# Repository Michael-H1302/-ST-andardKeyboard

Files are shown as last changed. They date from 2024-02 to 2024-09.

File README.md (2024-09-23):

A custom keyboard design made with KiCad. The Design uses a STM32 Blue Pill Microcontroller featuring red led backlight that can be controlled in three groups (two rows per group). Don't get confused by the name HotKeyBoard. I just made use of some previous work and derived it from an already existing KiCad project. 
The keyboard design supports standard mechanical switches like the Cherry MX and the Gateron. Due to the LED placement below the actual switch footprint, even switches without an
extra space for the LED are supported.

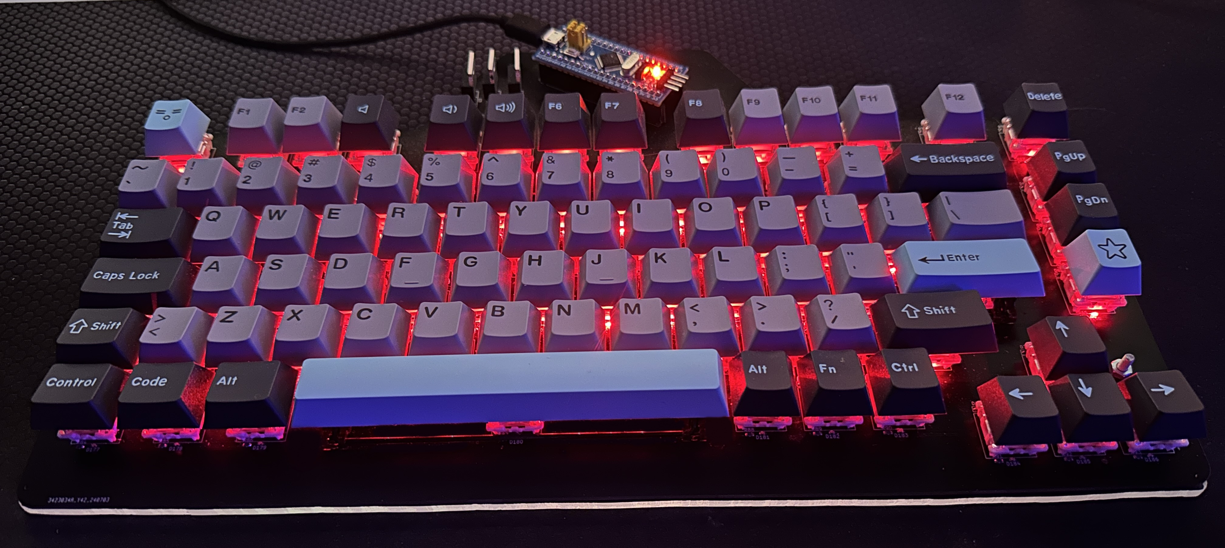
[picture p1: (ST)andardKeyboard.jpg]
Keyboard


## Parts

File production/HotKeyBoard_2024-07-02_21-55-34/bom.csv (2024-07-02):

Designator | Footprint | Quantity | Value | LCSC Part #
D1, D10, D11, D12, D13, D14, D15, D16, D17, D18, D19, D2, D20, D21, D22, D23, D24, D25, D26, D27, D28, D29, D3, D30, D31, D32, D33, D34, D35, D36, D37, D38, D39, D4, D40, D41, D42, D43, D44, D45, D46, D47, D48, D49, D5, D50, D51, D52, D53, D54, D55, D56, D57, D58, D59, D6, D60, D61, D62, D63, D64, D65, D67, D68, D69, D7, D70, D71, D73, D74, D75, D76, D77, D79, D8, D80, D81, D82, D83, D86, D87, D9 | D_SOD-323 | 82 | D
D100, D101, D102, D103, D104, D105, D106, D107, D108, D109, D110, D113, D114, D115, D116, D117, D118, D119, D120, D121, D122, D123, D124, D125, D126, D127, D129, D130, D131, D132, D133, D134, D135, D136, D137, D138, D139, D140, D141, D142, D143, D145, D146, D147, D148, D149, D150, D151, D152, D153, D154, D155, D156, D157, D158, D161, D162, D163, D164, D165, D166, D167, D168, D169, D170, D171, D172, D173, D174, D177, D178, D179, D180, D181, D182, D183, D184, D185, D186, D97, D98, D99 | 0402 | 82 | LED | C71911
H1, H2, H3, H4 | MountingHole_3.2mm_M3_DIN965 | 4 | MountingHole
J2, J3 | PinHeader_1x20_P2.54mm_Vertical | 2 | Conn_01x20_Pin
J4, J5, J6 | PinHeader_1x02_P2.54mm_Vertical | 3 | Conn_01x02_Socket
Q1, Q2, Q3 | TO-220-3_Vertical | 3 | IRLZ34N | C538198
R1 | R_Axial_DIN0204_L3.6mm_D1.6mm_P5.08mm_Horizontal | 1 | R
R10, R11, R12, R13, R14, R15, R16, R17, R20, R21, R22, R23, R24, R25, R26, R27, R28, R29, R30, R31, R32, R33, R34, R36, R37, R38, R39, R4, R40, R41, R42, R43, R44, R45, R46, R47, R48, R49, R5, R50, R52, R53, R54, R55, R56, R57, R58, R59, R6, R60, R61, R62, R63, R64, R65, R68, R69, R7, R70, R71, R72, R73, R74, R75, R76, R77, R78, R79, R8, R80, R81, R84, R85, R86, R87, R88, R89, R9, R90, R91, R92, R93 | 0603 | 82 | R | C101269
SW1, SW10, SW11, SW13, SW14, SW15, SW16, SW17, SW19, SW2, SW20, SW21, SW22, SW23, SW25, SW26, SW27, SW28, SW29, SW30, SW31, SW32, SW33, SW34, SW35, SW36, SW37, SW38, SW39, SW40, SW41, SW42, SW43, SW44, SW45, SW46, SW47, SW48, SW49, SW50, SW51, SW52, SW53, SW54, SW55, SW56, SW57, SW58, SW59, SW60, SW61, SW62, SW63, SW64, SW65, SW67, SW68, SW69, SW7, SW70, SW76, SW77, SW78, SW8, SW80, SW82, SW85, SW86, SW89, SW9, SW90 | SW_Cherry_MX_1.00u_PCB | 71 | SW_Push
SW12, SW18, SW5, SW6 | SW_Cherry_MX_1.25u_PCB | 4 | SW_Push
SW24 | SW_Cherry_MX_6.25u_PCB | 1 | SW_Push
SW3, SW84 | SW_Cherry_MX_1.50u_PCB | 2 | SW_Push
SW4, SW71 | SW_Cherry_MX_1.75u_PCB | 2 | SW_Push
SW79 | SW_Cherry_MX_2.25u_PCB | 1 | SW_Push
SW83 | SW_Cherry_MX_2.00u_PCB | 1 | SW_Push

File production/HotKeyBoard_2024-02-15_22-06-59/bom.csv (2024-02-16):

Designator | Footprint | Quantity | Value | LCSC Part #
D1, D10, D100, D101, D102, D103, D104, D105, D106, D107, D108, D109, D11, D110, D111, D112, D113, D114, D115, D116, D117, D118, D119, D12, D120, D121, D122, D123, D124, D125, D126, D127, D128, D129, D13, D130, D131, D132, D133, D134, D135, D136, D137, D138, D139, D14, D140, D141, D142, D143, D144, D15, D16, D17, D18, D19, D2, D20, D21, D22, D23, D24, D25, D26, D27, D28, D29, D3, D30, D31, D32, D33, D34, D35, D36, D37, D38, D39, D4, D40, D41, D42, D43, D44, D45, D46, D47, D48, D49, D5, D50, D51, D52, D53, D54, D55, D56, D57, D58, D59, D6, D60, D61, D62, D63, D64, D65, D66, D67, D68, D69, D7, D70, D71, D72, D73, D74, D75, D76, D77, D78, D79, D8, D80, D81, D82, D83, D84, D85, D86, D87, D88, D89, D9, D90, D91, D92, D93, D94, D95, D96, D97, D98, D99 | D_SOD-323 | 144 | D
J1, J2 | PinHeader_1x12_P2.54mm_Vertical | 2 | Conn_01x12_Socket
SW1, SW10, SW11, SW12, SW13, SW14, SW15, SW16, SW17, SW18, SW19, SW2, SW20, SW21, SW22, SW23, SW24, SW25, SW26, SW27, SW28, SW29, SW3, SW30, SW31, SW32, SW33, SW34, SW35, SW36, SW37, SW38, SW39, SW4, SW40, SW41, SW42, SW43, SW44, SW45, SW46, SW47, SW48, SW5, SW53, SW54, SW55, SW56, SW57, SW58, SW59, SW6, SW60, SW61, SW65, SW7, SW70, SW71, SW72, SW8, SW9 | SW_Cherry_MX_1.00u_PCB | 61 | SW_Push
SW49, SW50, SW51 | SW_Cherry_MX_1.25u_PCB | 3 | SW_Push
SW52 | SW_Cherry_MX_6.25u_PCB | 1 | SW_Push
SW62, SW67 | SW_Cherry_MX_1.50u_PCB | 2 | SW_Push
SW63, SW69 | SW_Cherry_MX_1.75u_PCB | 2 | SW_Push
SW64, SW68 | SW_Cherry_MX_2.25u_PCB | 2 | SW_Push
SW66 | SW_Cherry_MX_2.00u_PCB | 1 | SW_Push

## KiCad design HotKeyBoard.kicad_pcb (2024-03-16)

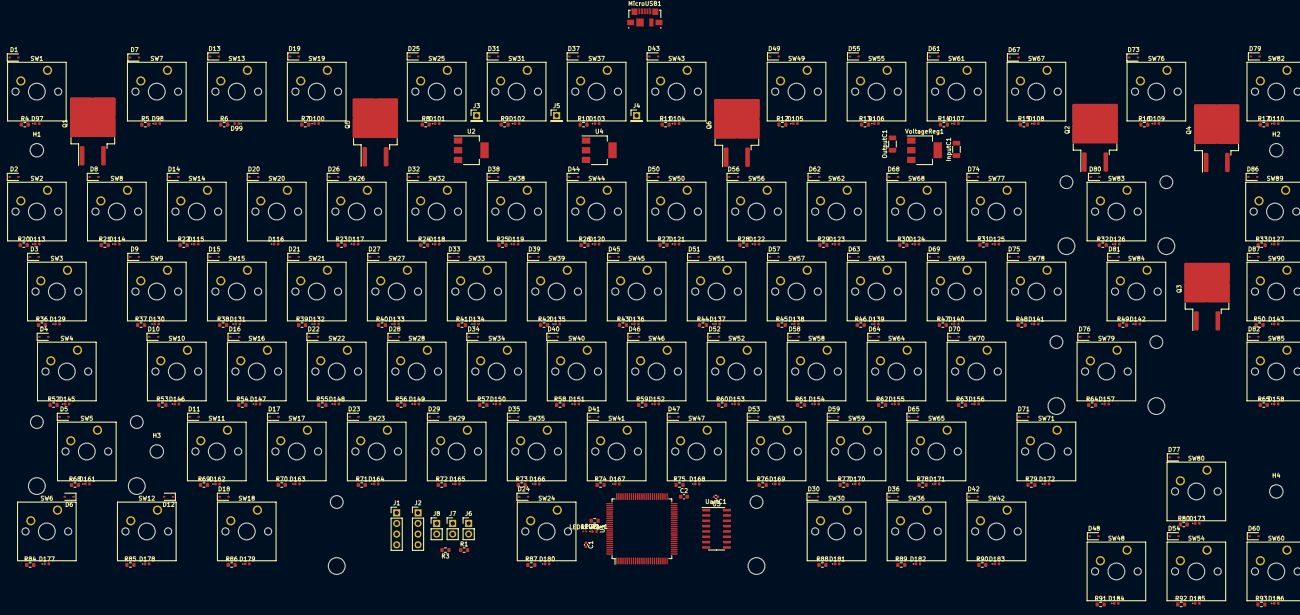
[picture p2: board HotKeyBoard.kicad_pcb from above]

Board: 2 copper layers, 357 parts (0 on the bottom side), 211 nets, no tracks yet.

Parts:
C1: 0.1uF; C_0402_1005Metric
C2: 1uF; C_0603_1608Metric
D1, D2, D3, D4, D5, D6, D7, D8, D9, D10, D11, D12, D13, D14, D15, D16, D17, D18, D19, D20, D21, D22, D23, D24, D25, D26, D27, D28, D29, D30, D31, D32, D33, D34, D35, D36, D37, D38, D39, D40, D41, D42, D43, D44, D45, D46, D47, D48, D49, D50, D51, D52, D53, D54, D55, D56, D57, D58, D59, D60, D61, D62, D63, D64, D65, D67, D68, D69, D70, D71, D73, D74, D75, D76, D77, D79, D80, D81, D82, D86, D87: D; D_SOD-323
D97, D98, D99, D100, D101, D102, D103, D104, D105, D106, D107, D108, D109, D110, D113, D114, D115, D116, D117, D118, D119, D120, D121, D122, D123, D124, D125, D126, D127, D129, D130, D131, D132, D133, D134, D135, D136, D137, D138, D139, D140, D141, D142, D143, D145, D146, D147, D148, D149, D150, D151, D152, D153, D154, D155, D156, D157, D158, D161, D162, D163, D164, D165, D166, D167, D168, D169, D170, D171, D172, D173, D177, D178, D179, D180, D181, D182, D183, D184, D185, D186: LED; LED_0402_1005Metric
H1, H2, H3, H4: MountingHole; MountingHole_3.2mm_M3_DIN965
InputC1: 100uF; C_1206_3216Metric
J1, J2: Conn_01x04_Pin; PinHeader_1x04_P2.54mm_Vertical
J3: USB_VOLTAGE Measuring Point; PinHeader_1x01_P2.54mm_Vertical
J4: LED_VOLTAGE Measuring Point 1; PinHeader_1x01_P2.54mm_Vertical
J5: LED_VOLTAGE Measuring Point 2; PinHeader_1x01_P2.54mm_Vertical
J6, J7, J8: Conn_01x02_Pin; PinHeader_1x02_P2.54mm_Vertical
LEDPwr1: LED; LED_0402_1005Metric
LEDRPwr1: 65; R_0201_0603Metric
MicroUSB1: USB_OTG; USB_Micro-B_Molex_47346-0001
OutputC1: 100uF; C_1206_3216Metric
Q1, Q2, Q3, Q4, Q5, Q6: IRLZ34N; TO-263-2
R1, R2, R3: 10k; R_0603_1608Metric
R4, R5, R6, R7, R8, R9, R10, R11, R12, R13, R14, R15, R16, R17, R20, R21, R22, R23, R24, R25, R26, R27, R28, R29, R30, R31, R32, R33, R36, R37, R38, R39, R40, R41, R42, R43, R44, R45, R46, R47, R48, R49, R50, R52, R53, R54, R55, R56, R57, R58, R59, R60, R61, R62, R63, R64, R65, R68, R69, R70, R71, R72, R73, R74, R75, R76, R77, R78, R79, R80, R84, R85, R86, R87, R88, R89, R90, R91, R92, R93: R; R_0603_1608Metric
SW1, SW2, SW7, SW8, SW9, SW10, SW11, SW13, SW14, SW15, SW16, SW17, SW19, SW20, SW21, SW22, SW23, SW25, SW26, SW27, SW28, SW29, SW30, SW31, SW32, SW33, SW34, SW35, SW36, SW37, SW38, SW39, SW40, SW41, SW42, SW43, SW44, SW45, SW46, SW47, SW48, SW49, SW50, SW51, SW52, SW53, SW54, SW55, SW56, SW57, SW58, SW59, SW60, SW61, SW62, SW63, SW64, SW65, SW67, SW68, SW69, SW70, SW76, SW77, SW78, SW80, SW82, SW85, SW89, SW90: SW_Push; SW_Cherry_MX_1.00u_PCB
SW3, SW84: SW_Push; SW_Cherry_MX_1.50u_PCB
SW4, SW71: SW_Push; SW_Cherry_MX_1.75u_PCB
SW5, SW79: SW_Push; SW_Cherry_MX_2.25u_PCB
SW6, SW12, SW18: SW_Push; SW_Cherry_MX_1.25u_PCB
SW24: SW_Push; SW_Cherry_MX_6.25u_PCB
SW83: SW_Push; SW_Cherry_MX_2.00u_PCB
U1: STM32F103VBTx; LQFP-100_14x14mm_P0.5mm
U2, U4: AMS1117-3.3; SOT-223-3_TabPin2
U3: CH340C; SOIC-16_3.9x9.9mm_P1.27mm
UartC1: 0.1uF; C_0402_1005Metric
VoltageReg1: AMS1117-3.3; SOT-223-3_TabPin2

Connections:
3.3V: C1.2, C2.1, J1.4, J2.4, J7.1, LEDRPwr1.1, OutputC1.1, R1.1, R3.1, U1.6 (VBAT), U1.11 (VDD), U1.21 (VREF+), U1.22 (VDDA), U1.28 (VDD), U1.50 (VDD), U1.75 (VDD), U1.100 (VDD), U3.4 (V3), U3.16 (VCC), UartC1.2, VoltageReg1.2 (VO)
Boot0: J7.2, R2.1, U1.94 (BOOT0)
Boot1: J8.2, R3.2, U1.37 (PB2)
Col0: SW1.1, SW2.1, SW3.1, SW4.1, SW5.1, SW6.1, U1.81 (PD0)
Col1: SW7.1, SW8.1, SW9.1, SW10.1, SW11.1, SW12.1, U1.82 (PD1)
Col2: SW13.1, SW14.1, SW15.1, SW16.1, SW17.1, SW18.1, U1.83 (PD2)
Col3: SW19.1, SW20.1, SW21.1, SW22.1, SW23.1, SW24.1, U1.84 (PD3)
Col4: SW25.1, SW26.1, SW27.1, SW28.1, SW29.1, SW30.1, U1.85 (PD4)
Col5: SW31.1, SW32.1, SW33.1, SW34.1, SW35.1, SW36.1, U1.86 (PD5)
Col6: SW37.1, SW38.1, SW39.1, SW40.1, SW41.1, SW42.1, U1.87 (PD6)
Col7: SW43.1, SW44.1, SW45.1, SW46.1, SW47.1, SW48.1, U1.88 (PD7)
Col8: SW49.1, SW50.1, SW51.1, SW52.1, SW53.1, SW54.1, U1.55 (PD8)
Col9: SW55.1, SW56.1, SW57.1, SW58.1, SW59.1, SW60.1, U1.56 (PD9)
Col10: SW61.1, SW62.1, SW63.1, SW64.1, SW65.1, U1.57 (PD10)
Col11: SW67.1, SW68.1, SW69.1, SW70.1, SW71.1, U1.58 (PD11)
Col12: SW76.1, SW77.1, SW78.1, SW79.1, SW80.1, U1.59 (PD12)
Col13: SW82.1, SW83.1, SW84.1, SW85.1, U1.60 (PD13)
Col14: SW89.1, SW90.1, U1.61 (PD14)
D+: MicroUSB1.3 (D+), U1.71 (PA12), U3.5 (UD+)
D-: MicroUSB1.2 (D-), U1.70 (PA11), U3.6 (UD-)
GND: C1.1, C2.2, InputC1.2, J1.3, J2.1, J6.1, J8.1, LEDPwr1.1 (K), MicroUSB1.5 (GND), OutputC1.2, Q1.3 (S), Q2.3 (S), Q3.3 (S), Q4.3 (S), Q5.3 (S), Q6.3 (S), R2.2, U1.10 (VSS), U1.19 (VSSA), U1.20 (VREF-), U1.27 (VSS), U1.49 (VSS), U1.74 (VSS), U1.99 (VSS), U2.1 (GND), U3.1 (GND), U4.1 (GND), UartC1.1, VoltageReg1.1 (GND)
Gate0: Q1.1 (G), U1.89 (PB3)
Gate1: Q2.1 (G), U1.90 (PB4)
Gate2: Q3.1 (G), U1.91 (PB5)
Gate3: Q4.1 (G), U1.63 (PC6)
Gate4: Q5.1 (G), U1.64 (PC7)
Gate5: Q6.1 (G), U1.65 (PC8)
I2C_SCL: J1.2, U1.47 (PB10)
I2C_SDA: J1.1, U1.48 (PB11)
LED_INPUT_VOLTAGE1: J4.1, R4.1, R5.1, R6.1, R7.1, R8.1, R9.1, R10.1, R11.1, R12.1, R13.1, R14.1, R15.1, R16.1, R17.1, R20.1, R21.1, R22.1, R23.1, R24.1, R25.1, R26.1, R27.1, R28.1, R29.1, R30.1, R31.1, R32.1, R33.1, R36.1, R37.1, R38.1, R39.1, R40.1, R41.1, R42.1, R43.1, R44.1, R45.1, R46.1, R47.1, R48.1, R49.1, R50.1, U2.2 (VO)
LED_INPUT_VOLTAGE2: J5.1, R52.1, R53.1, R54.1, R55.1, R56.1, R57.1, R58.1, R59.1, R60.1, R61.1, R62.1, R63.1, R64.1, R65.1, R68.1, R69.1, R70.1, R71.1, R72.1, R73.1, R74.1, R75.1, R76.1, R77.1, R78.1, R79.1, R80.1, R84.1, R85.1, R86.1, R87.1, R88.1, R89.1, R90.1, R91.1, R92.1, R93.1, U4.2 (VO)
Mosfet0: D97.1 (K), D98.1 (K), D99.1 (K), D100.1 (K), D101.1 (K), D102.1 (K), D103.1 (K), D104.1 (K), D105.1 (K), D106.1 (K), D107.1 (K), D108.1 (K), D109.1 (K), D110.1 (K), Q1.2 (D)
Mosfet1: D113.1 (K), D114.1 (K), D115.1 (K), D116.1 (K), D117.1 (K), D118.1 (K), D119.1 (K), D120.1 (K), D121.1 (K), D122.1 (K), D123.1 (K), D124.1 (K), D125.1 (K), D126.1 (K), D127.1 (K), Q2.2 (D)
Mosfet2: D129.1 (K), D130.1 (K), D131.1 (K), D132.1 (K), D133.1 (K), D134.1 (K), D135.1 (K), D136.1 (K), D137.1 (K), D138.1 (K), D139.1 (K), D140.1 (K), D141.1 (K), D142.1 (K), D143.1 (K), Q3.2 (D)
Mosfet3: D145.1 (K), D146.1 (K), D147.1 (K), D148.1 (K), D149.1 (K), D150.1 (K), D151.1 (K), D152.1 (K), D153.1 (K), D154.1 (K), D155.1 (K), D156.1 (K), D157.1 (K), D158.1 (K), Q4.2 (D)
Mosfet4: D161.1 (K), D162.1 (K), D163.1 (K), D164.1 (K), D165.1 (K), D166.1 (K), D167.1 (K), D168.1 (K), D169.1 (K), D170.1 (K), D171.1 (K), D172.1 (K), D173.1 (K), Q5.2 (D)
Mosfet5: D177.1 (K), D178.1 (K), D179.1 (K), D180.1 (K), D181.1 (K), D182.1 (K), D183.1 (K), D184.1 (K), D185.1 (K), D186.1 (K), Q6.2 (D)
NRST: J6.2, R1.2, U1.14 (NRST)
unnamed: D1.2 (A), SW1.2
unnamed: D2.2 (A), SW2.2
unnamed: D3.2 (A), SW3.2
unnamed: D4.2 (A), SW4.2
unnamed: D5.2 (A), SW5.2
unnamed: D6.2 (A), SW6.2
unnamed: D7.2 (A), SW7.2
unnamed: D8.2 (A), SW8.2
unnamed: D9.2 (A), SW9.2
unnamed: D10.2 (A), SW10.2
unnamed: D11.2 (A), SW11.2
unnamed: D12.2 (A), SW12.2
unnamed: D13.2 (A), SW13.2
unnamed: D14.2 (A), SW14.2
unnamed: D15.2 (A), SW15.2
unnamed: D16.2 (A), SW16.2
unnamed: D17.2 (A), SW17.2
unnamed: D18.2 (A), SW18.2
unnamed: D19.2 (A), SW19.2
unnamed: D20.2 (A), SW20.2
unnamed: D21.2 (A), SW21.2
unnamed: D22.2 (A), SW22.2
unnamed: D23.2 (A), SW23.2
unnamed: D24.2 (A), SW24.2
unnamed: D25.2 (A), SW25.2
unnamed: D26.2 (A), SW26.2
unnamed: D27.2 (A), SW27.2
unnamed: D28.2 (A), SW28.2
unnamed: D29.2 (A), SW29.2
unnamed: D30.2 (A), SW30.2
unnamed: D31.2 (A), SW31.2
unnamed: D32.2 (A), SW32.2
unnamed: D33.2 (A), SW33.2
unnamed: D34.2 (A), SW34.2
unnamed: D35.2 (A), SW35.2
unnamed: D36.2 (A), SW36.2
unnamed: D37.2 (A), SW37.2
unnamed: D38.2 (A), SW38.2
unnamed: D39.2 (A), SW39.2
unnamed: D40.2 (A), SW40.2
unnamed: D41.2 (A), SW41.2
unnamed: D42.2 (A), SW42.2
unnamed: D43.2 (A), SW43.2
unnamed: D44.2 (A), SW44.2
unnamed: D45.2 (A), SW45.2
unnamed: D46.2 (A), SW46.2
unnamed: D47.2 (A), SW47.2
unnamed: D48.2 (A), SW48.2
unnamed: D49.2 (A), SW49.2
unnamed: D50.2 (A), SW50.2
unnamed: D51.2 (A), SW51.2
unnamed: D52.2 (A), SW52.2
unnamed: D53.2 (A), SW53.2
unnamed: D54.2 (A), SW54.2
unnamed: D55.2 (A), SW55.2
unnamed: D56.2 (A), SW56.2
unnamed: D57.2 (A), SW57.2
unnamed: D58.2 (A), SW58.2
unnamed: D59.2 (A), SW59.2
unnamed: D60.2 (A), SW60.2
unnamed: D61.2 (A), SW61.2
unnamed: D62.2 (A), SW62.2
unnamed: D63.2 (A), SW63.2
unnamed: D64.2 (A), SW64.2
unnamed: D65.2 (A), SW65.2
unnamed: D67.2 (A), SW67.2
unnamed: D68.2 (A), SW68.2
unnamed: D69.2 (A), SW69.2
unnamed: D70.2 (A), SW70.2
unnamed: D71.2 (A), SW71.2
unnamed: D73.2 (A), SW76.2
unnamed: D74.2 (A), SW77.2
unnamed: D75.2 (A), SW78.2
unnamed: D76.2 (A), SW79.2
unnamed: D77.2 (A), SW80.2
unnamed: D79.2 (A), SW82.2
unnamed: D80.2 (A), SW83.2
unnamed: D81.2 (A), SW84.2
unnamed: D82.2 (A), SW85.2
unnamed: D86.2 (A), SW89.2
unnamed: D87.2 (A), SW90.2
unnamed: D97.2 (A), R4.2
unnamed: D98.2 (A), R5.2
unnamed: D99.2 (A), R6.2
unnamed: D100.2 (A), R7.2
unnamed: D101.2 (A), R8.2
unnamed: D102.2 (A), R9.2
unnamed: D103.2 (A), R10.2
unnamed: D104.2 (A), R11.2
unnamed: D105.2 (A), R12.2
unnamed: D106.2 (A), R13.2
unnamed: D107.2 (A), R14.2
unnamed: D108.2 (A), R15.2
unnamed: D109.2 (A), R16.2
unnamed: D110.2 (A), R17.2
unnamed: D113.2 (A), R20.2
unnamed: D114.2 (A), R21.2
unnamed: D115.2 (A), R22.2
unnamed: D116.2 (A), R23.2
unnamed: D117.2 (A), R24.2
unnamed: D118.2 (A), R25.2
unnamed: D119.2 (A), R26.2
unnamed: D120.2 (A), R27.2
unnamed: D121.2 (A), R28.2
unnamed: D122.2 (A), R29.2
unnamed: D123.2 (A), R30.2
unnamed: D124.2 (A), R31.2
unnamed: D125.2 (A), R32.2
unnamed: D126.2 (A), R33.2
unnamed: D129.2 (A), R36.2
unnamed: D130.2 (A), R37.2
unnamed: D131.2 (A), R38.2
unnamed: D132.2 (A), R39.2
unnamed: D133.2 (A), R40.2
unnamed: D134.2 (A), R41.2
unnamed: D135.2 (A), R42.2
unnamed: D136.2 (A), R43.2
unnamed: D137.2 (A), R44.2
unnamed: D138.2 (A), R45.2
unnamed: D139.2 (A), R46.2
unnamed: D140.2 (A), R47.2
unnamed: D141.2 (A), R48.2
unnamed: D142.2 (A), R49.2
unnamed: D143.2 (A), R50.2
unnamed: D145.2 (A), R52.2
unnamed: D146.2 (A), R53.2
unnamed: D147.2 (A), R54.2
unnamed: D148.2 (A), R55.2
unnamed: D149.2 (A), R56.2
unnamed: D150.2 (A), R57.2
unnamed: D151.2 (A), R58.2
unnamed: D152.2 (A), R59.2
unnamed: D153.2 (A), R60.2
unnamed: D154.2 (A), R61.2
unnamed: D155.2 (A), R62.2
unnamed: D156.2 (A), R63.2
unnamed: D157.2 (A), R64.2
unnamed: D158.2 (A), R65.2
unnamed: D161.2 (A), R68.2
unnamed: D162.2 (A), R69.2
unnamed: D163.2 (A), R70.2
unnamed: D164.2 (A), R71.2
unnamed: D165.2 (A), R72.2
unnamed: D166.2 (A), R73.2
unnamed: D167.2 (A), R74.2
unnamed: D168.2 (A), R75.2
unnamed: D169.2 (A), R76.2
unnamed: D170.2 (A), R77.2
unnamed: D171.2 (A), R78.2
unnamed: D172.2 (A), R79.2
unnamed: D173.2 (A), R80.2
unnamed: D177.2 (A), R84.2
unnamed: D178.2 (A), R85.2
unnamed: D179.2 (A), R86.2
unnamed: D180.2 (A), R87.2
unnamed: D181.2 (A), R88.2
unnamed: D182.2 (A), R89.2
unnamed: D183.2 (A), R90.2
unnamed: D184.2 (A), R91.2
unnamed: D185.2 (A), R92.2
unnamed: D186.2 (A), R93.2
unnamed: LEDPwr1.2 (A), LEDRPwr1.2
RX: U1.68 (PA9), U3.3 (RXD)
Row0: D1.1 (K), D7.1 (K), D13.1 (K), D19.1 (K), D25.1 (K), D31.1 (K), D37.1 (K), D43.1 (K), D49.1 (K), D55.1 (K), D61.1 (K), D67.1 (K), D73.1 (K), D79.1 (K), U1.97 (PE0)
Row1: D2.1 (K), D8.1 (K), D14.1 (K), D20.1 (K), D26.1 (K), D32.1 (K), D38.1 (K), D44.1 (K), D50.1 (K), D56.1 (K), D62.1 (K), D68.1 (K), D74.1 (K), D80.1 (K), D86.1 (K), U1.98 (PE1)
Row2: D3.1 (K), D9.1 (K), D15.1 (K), D21.1 (K), D27.1 (K), D33.1 (K), D39.1 (K), D45.1 (K), D51.1 (K), D57.1 (K), D63.1 (K), D69.1 (K), D75.1 (K), D81.1 (K), D87.1 (K), U1.1 (PE2)
Row3: D4.1 (K), D10.1 (K), D16.1 (K), D22.1 (K), D28.1 (K), D34.1 (K), D40.1 (K), D46.1 (K), D52.1 (K), D58.1 (K), D64.1 (K), D70.1 (K), D76.1 (K), D82.1 (K), U1.2 (PE3)
Row4: D5.1 (K), D11.1 (K), D17.1 (K), D23.1 (K), D29.1 (K), D35.1 (K), D41.1 (K), D47.1 (K), D53.1 (K), D59.1 (K), D65.1 (K), D71.1 (K), D77.1 (K), U1.3 (PE4)
Row5: D6.1 (K), D12.1 (K), D18.1 (K), D24.1 (K), D30.1 (K), D36.1 (K), D42.1 (K), D48.1 (K), D54.1 (K), D60.1 (K), U1.4 (PE5)
SWCLK: J2.2, U1.76 (PA14)
SWDIO: J2.3, U1.72 (PA13)
TX: U1.69 (PA10), U3.2 (TXD)
USB_VOLT: InputC1.1, J3.1, MicroUSB1.1 (VBUS), U2.3 (VI), U4.3 (VI), VoltageReg1.3 (VI)

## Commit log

2024-02-11 Inital layout
    [HotKeyBoard.kicad_pcb, HotKeyBoard.kicad_sch]
2024-02-15 Moved function key
    [HotKeyBoard.kicad_pcb, HotKeyBoard.kicad_sch]
2024-02-16 Changed to 75 layout without function row, but added makro column instead
    [HotKeyBoard.kicad_pcb, bom.csv, designators.csv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]
2024-02-16 Added mounting holes
    [HotKeyBoard.kicad_pcb, HotKeyBoard.kicad_sch]
2024-03-02 Fixed bug in keyboard matrix
    [HotKeyBoard.kicad_pcb, HotKeyBoard.kicad_sch, bom.csv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]
2024-03-02 Fixed matrix design
    [HotKeyBoard.kicad_pcb, bom.csv, designators.csv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]
2024-03-11 Final production layout
    [HotKeyBoard.kicad_pcb, bom.csv, designators.csv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]
2024-03-15 Started doing the schematic
    [HotKeyBoard.kicad_sch]
2024-03-16 Finished schematic
    [HotKeyBoard.kicad_sch]
2024-03-16 Started layout
    [HotKeyBoard.kicad_pcb, HotKeyBoard.kicad_sch]
2024-03-17 Continued layout, deleted firmware
    [HotKeyBoard.kicad_sch]
2024-03-23 Finished single sided layout
    [HotKeyBoard.kicad_sch, bom.csv, designators.csv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]
2024-04-10 Added overbridging of mosfets
    [HotKeyBoard.kicad_sch]
2024-04-10 Added THT micro usb
    [HotKeyBoard.kicad_sch]
2024-04-11 Changed micro usb port
    [HotKeyBoard.kicad_sch]
2024-04-12 Switched micro usb again
    [HotKeyBoard.kicad_sch]
2024-04-20 Finished layout
    [HotKeyBoard.kicad_sch]
2024-04-20 Fixed resistor
    [HotKeyBoard.kicad_sch]
2024-04-21 Added multiple mosfets
    [HotKeyBoard.kicad_sch]
2024-04-21 Rewired leds
    [HotKeyBoard.kicad_sch]
2024-04-21 Changed led resistor to smaller value to give pwm control more range to play with
    [HotKeyBoard.kicad_sch]
2024-04-22 Increased track width for led power delivery
2024-04-23 Added 0ohm resistor before the last led row in order to be able to turn it off
    [HotKeyBoard.kicad_sch]
2024-07-02 Added name and version to the pcb
    [bom.csv, designators.csv, positions.csv]
2024-09-23 Fixed some layout issues with a single misplaced led and the resistor for disabling the last led row
